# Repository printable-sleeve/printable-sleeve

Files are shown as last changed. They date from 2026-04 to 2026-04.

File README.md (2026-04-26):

# PRINTABLE-SLEEVE

**Open Source Sexual Wellness Device**

A parametric, vacuum-enabled masturbation sleeve for FDM 3D printing. Two materials.
Five parts. No proprietary components. Fully open source.

> ⚠️ **Adult use only.** This project contains technical documentation
> for a personal wellness device intended for adults.

→ [Why this project exists](WHY.md)

---

## Download ready-to-print STL files

Pre-rendered for four standard sizes. All parts per size are matched and fit together.

| Size | BORE_D | Girth | Files |
|---|---|---|---|
| **S** | 35.0 mm | ~110 mm | shell_S, cap_S, plug_S, inlay_S, cushion_S |
| **M** | 38.0 mm | ~119 mm | shell_M, cap_M, plug_M, inlay_M, cushion_M |
| **L** | 41.0 mm | ~129 mm | shell_L, cap_L, plug_L, inlay_L, cushion_L |
| **XL** | 44.0 mm | ~138 mm | shell_XL, cap_XL, plug_XL, inlay_XL, cushion_XL |

Download all STLs from the [Files page](https://github.com/printable-sleeve/printable-sleeve/tree/main/files).

Not sure which size? Wrap a soft tape around your shaft, note the girth in mm, divide by 3.14.
Pick the size closest to your result. TPU stretches slightly — when between sizes, go smaller.

---

## What you need

| | |
|---|---|
| 3D printer | FDM — e.g. Bambu Lab A1 Mini |
| Material A | PETG (shell + cap) |
| Material B | TPU Shore 95A, body-safe, phthalate-free |
| Software | [OpenSCAD](https://openscad.org) + [BOSL2 library](https://github.com/BelfrySCAD/BOSL2) |
| Accessories | Water-based lubricant, condom (recommended) |

---

## How it works

The device consists of five printed parts:

```
A) shell   → PETG rigid housing
B) cap     → PETG screw cap with vacuum port
C) plug    → TPU vacuum seal
D) inlay   → TPU sleeve with soft entry ring
E) cushion → TPU air cushion ring (optional)
```

The inlay protrudes from the front of the shell. The cap screws onto the rear.
Inserting the plug creates a vacuum inside — which applies gentle pressure
from all sides and holds the inlay in place.

---

## Custom size — build from source

### Step 1 — Measure yourself

Wrap a soft tape around your shaft. Note the girth in mm.
Divide by 3.14 → that is your diameter. Enter it as `BORE_D`.

**Example:** 124 mm girth ÷ 3.14 = **39.5 mm**

> **Note:** `BORE_D` sets the housing size, not the inlay bore directly.
> The actual bore inside the inlay is approximately `BORE_D − 6.4 mm` with default settings.
> TPU Shore 95A stretches to accommodate — this is intentional.
> Reduce `WALL_T` for a looser fit, increase for firmer.

### Step 2 — Install BOSL2

1. [Download BOSL2](https://github.com/BelfrySCAD/BOSL2/archive/refs/heads/master.zip)
2. Unzip, rename the folder to `BOSL2`
3. Copy to your OpenSCAD libraries folder:
   - **Windows:** `Documents/OpenSCAD/libraries/`
   - **Linux:** `~/.local/share/OpenSCAD/libraries/`
   - **Mac:** `~/Documents/OpenSCAD/libraries/`

### Step 3 — Customise the file

Open `PRINTABLE-SLEEVE.scad` in OpenSCAD. Change these values near the top:

```openscad
BORE_D       = 39.5;   // ← your diameter (girth ÷ 3.14)
SHRINK_COMP  = 1.00;   // ← start here, tune if inlay is too loose or tight
WALL_T       = 5.5;    // ← wall thickness (increase for firmer feel)
SHELL_LENGTH = 100.0;  // ← 80 / 100 / 120 mm
```

### Step 4 — Export each part as STL

Set `RENDER = "..."` → **Design → Export → Export as STL**

| RENDER | Material | Print time |
|---|---|---|
| `"shell"` | PETG | ~90 min |
| `"cap"` | PETG | ~60 min |
| `"plug"` | TPU | ~15 min |
| `"inlay"` | TPU | ~120 min |
| `"cushion"` | TPU | ~60 min (optional) |

Use `RENDER = "all"` to preview all parts together (not for printing).

---

## Print settings

### PETG — shell + cap

| Setting | Value |
|---|---|
| Nozzle | 250–255°C |
| Bed | 70°C, textured PEI + glue stick |
| Layer height | 0.20 mm |
| Walls | 4 |
| Infill | 40% |

### TPU Shore 95A — inlay + plug + cushion

**Filament profile** (filament → pencil icon → tabs):

| Setting | Tab | Value |
|---|---|---|
| Nozzle | Temperature | 225°C |
| Bed | Temperature | 30°C, smooth PEI |
| **Retraction length** | Retraction | **0.4 mm** ← critical |
| Flow rate | Advanced | 95% |
| Max volumetric speed | Advanced | 1.5 mm³/s |
| Wall lines | Strength | 2 |
| Infill density | Strength | 10% gyroid |
| AMS Lite | — | **DO NOT USE** — external spool only |

**Process profile:**

| Setting | Location | Value |
|---|---|---|
| Layer height | Quality | 0.20 mm |
| Seam position | Quality | Nearest |
| Wall order | Quality → Advanced | outer/inner |
| **Avoid crossing walls** | Quality → Advanced | **ON** ← critical |
| Outer wall speed | Speed | 80 mm/s |
| Inner wall speed | Speed | 80 mm/s |
| Surface speed | Speed | 80 mm/s |
| Reduce infill retraction | Other → G-Code | ON |

**Printer settings** (printer profile → Extruder tab):

| Setting | Value |
|---|---|
| Retraction length | 0.4 mm |
| Z-hop | 0.2 mm |
| Retraction/feed speed | 30 mm/s |

> **Air cushion only:** set infill to **0%** and top/bottom layers to **4**.

### Print orientation

| Part | Place on bed |
|---|---|
| Shell | upright, open end up |
| Cap | flat side down |
| Plug | grip head down, pin up |
| Inlay | insertion end down (z=0), opening up |

---

## Assembly

1. (Optional) Push air cushion ring into shell bore
2. Push inlay into shell from front until it seats on the rim
3. Screw cap onto rear thread
4. Push plug into cap vacuum port → vacuum builds up inside

---

## Use

- **Water-based lubricant only** — silicone lubricant degrades TPU
- Condom recommended (improves hygiene and feel)
- Apply lubricant to inlay bore before use

---

## Cleaning

1. Pull inlay straight out
2. Rinse with warm soapy water
3. Dry completely before reinserting
4. Shell: wipe with damp cloth — do not submerge
5. Replace inlay if you see cracks or permanent deformation

---

## Post-processing (optional)

Sand the inner bore of the inlay with wet/dry paper:
**400 grit → 800 grit → 1200 grit**
Takes 2–3 minutes. Removes seam ridges for a smoother surface.

---

## Parameters

| Parameter | Default | What it controls |
|---|---|---|
| `BORE_D` | 39.5 | Inner bore diameter [mm] — your girth ÷ 3.14 |
| `SHELL_LENGTH` | 100 | Shell length [mm] |
| `SHRINK_COMP` | 1.00 | TPU shrinkage factor — tune in 0.005 steps |
| `WALL_T` | 5.5 | Wall thickness [mm] — thicker = firmer |
| `RENDER` | "inlay" | Which part to export as STL |
| `RESOLUTION` | 64 | Render quality (64 recommended) |

---

## Troubleshooting

| Problem | Solution |
|---|---|
| Inlay too loose in shell | Increase `SHRINK_COMP` by 0.005 |
| Inlay won't fit in shell | Decrease `SHRINK_COMP` by 0.005 |
| Stringing inside bore | Retraction 0 mm + Avoid crossing walls ON |
| Surface bumps inside bore | Flow rate 92%, speed 12 mm/s |
| Vacuum won't hold | Push plug in further, tighten cap |

---

## Optional: Air Cushion Ring

Set `RENDER = "cushion"`. Insert into shell bore before the inlay.
Acts as a soft spring — compresses under load, rebounds when released.
Stack 1 or 2 rings to tune resistance.

**Critical:** infill **0%** — the hollow wall is the spring.

---

## License

**Creative Commons Attribution-ShareAlike 4.0 International (CC BY-SA 4.0)**

Free to use, modify, and share — including commercially.
Attribution required. Derivatives must carry the same license.

Full text: https://creativecommons.org/licenses/by-sa/4.0/

---

## Disclaimer

This project is provided as-is for educational and personal use.This device has not been tested, certified, or approved by any medical or regulatory body. The authors make no warranties regarding safety, fitness for purpose, or material compatibility. You are solely responsible for the materials you use, the quality of your print, and how you use the device. Use body-safe, phthalate-free TPU from a reputable supplier — the authors cannot verify third-party materials. If you experience any discomfort, discontinue use immediately. This project is not a medical device. By downloading, printing, or using this design you accept full responsibility for your own safety.

---

## Contributing

Pull requests welcome. Please keep changes parametric and document
any new parameters in the file header and in this README.

---

*printable-sleeve — Open Source Sexual Wellness*
*https://github.com/printable-sleeve*

---

This design is free. If it works for you and you'd like to support the project:
❤️ https://buymeacoffee.com/uknawn

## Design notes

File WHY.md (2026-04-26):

# Why printable-sleeve exists

Sexual wellness products are a $1.5 billion market growing at 9.5% annually.
Yet for millions of people, buying one is still out of reach — not because
the products don't exist, but because of price, stigma, and geography.

This project exists to change that.

---

## The three barriers we eliminate

### 1. Cost

A commercial masturbation sleeve costs €60–90.
The materials to print one cost €2–5.

That gap exists not because of engineering complexity, but because of
marketing, distribution, retail margins, and packaging. None of those
add any functional value for the person using it.

FDM printing eliminates all of them.

### 2. Stigma

Studies show that approximately 29% of people who want a sexual wellness
product never buy one — not because of price, but because of stigma.

The act of buying one is itself a barrier:
walking into a shop, receiving a package, seeing a charge on a bank statement.

A file you download and print at home leaves no trace.
That is not a workaround. That is a genuine solution to a real problem.

### 3. Access

A person in a rural area, a country with restrictive import laws,
or simply without disposable income has no realistic access to this
product category at commercial prices.

A 3D printer and a spool of TPU changes that.
The design travels as a file. Manufacturing happens locally, on demand.

---

## The health case

This is not just about convenience or cost. There is a documented
public health argument.

A study published in European Urology (Rider et al., 2016, based on
Harvard/Health Professionals Follow-up data) found that men who
ejaculated 21 or more times per month had a 20% lower risk of
prostate cancer compared to those who ejaculated 4–7 times per month.

Separate research consistently links sexual activity and orgasm with
reduced cortisol levels, improved sleep quality, and lower cardiovascular
stress markers.

Access to appropriate tools matters for these outcomes.
A product that is unaffordable or inaccessible is not a solution.

---

## Why open source

Commercial products in this category are closed, proprietary, and
designed to be replaced rather than repaired or customised.

Open source means:
- Anyone can adapt the design for their body
- Anyone can improve it and share the improvement
- No company can restrict access or raise prices
- The design survives its creator

We use CC BY-SA 4.0. You can use this design, modify it, and even
sell prints of it — as long as you keep it open under the same terms.

---

## Why now

Two things made this possible:

**Bambu Lab (2022–2024)** democratised FDM printing. A machine that
produces reliable, accurate prints at 15 mm/s in TPU now costs under €200.
That did not exist five years ago.

**OpenSCAD + BOSL2** makes the design fully parametric. One number —
your girth divided by 3.14 — adapts the entire geometry to your body.
No CAD skills required.

The technology was always theoretically possible. Now it is practical.

---

## What this is not

This is not a replacement for human connection.
This is not a statement about relationships or sexuality.
This is a functional object, designed to be printed, used, and improved.

The same argument that applies here applies to any product where:
- There is a large gap between manufacturing cost and retail price
- Stigma reduces access for people who would benefit
- The underlying technology is now accessible to individuals

Sexual wellness happens to be a particularly clear example.
But the principle is general.

---

## Contributing

If you improve this design, please share it under the same license.
If you print it and have feedback, open an issue.
If you know someone who would benefit from this, share the link.

That is how open source works.

---

*printable-sleeve — Open Source Sexual Wellness*
*CC BY-SA 4.0 — https://github.com/printable-sleeve*

---

This design is free. If it works for you and you'd like to support the project:
❤️ https://buymeacoffee.com/uknawn

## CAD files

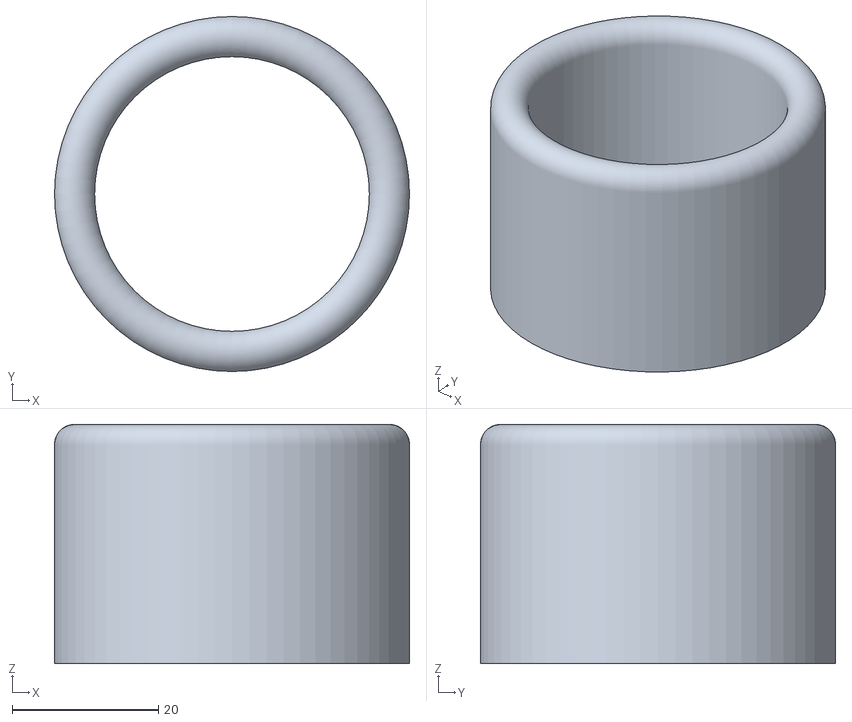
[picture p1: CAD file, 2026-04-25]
files/inlay_XL.stl
48.6 x 48.6 x 32.8

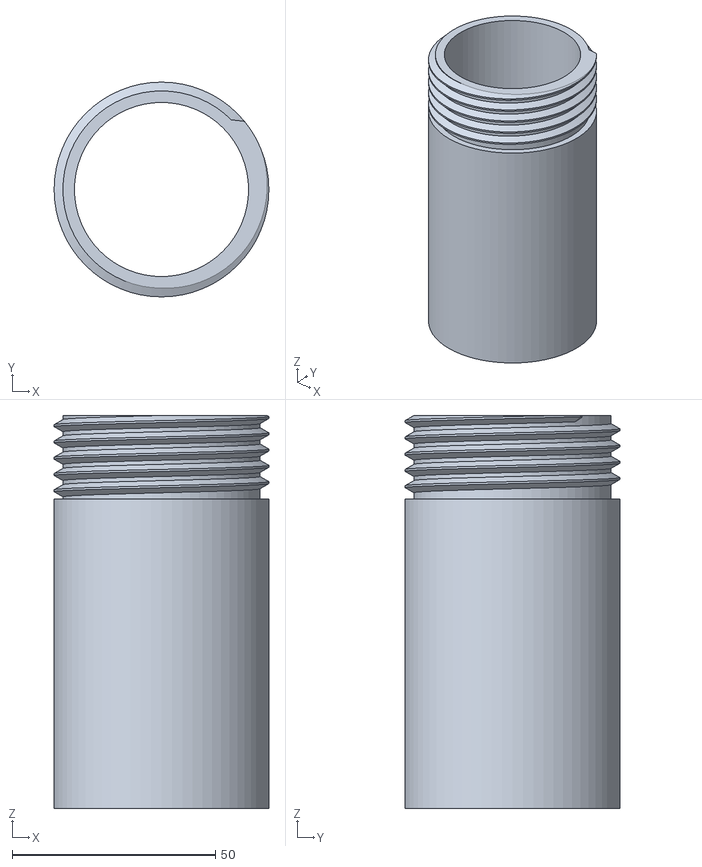
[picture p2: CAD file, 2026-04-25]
files/shell_M.stl
52.8 x 52.8 x 96.6

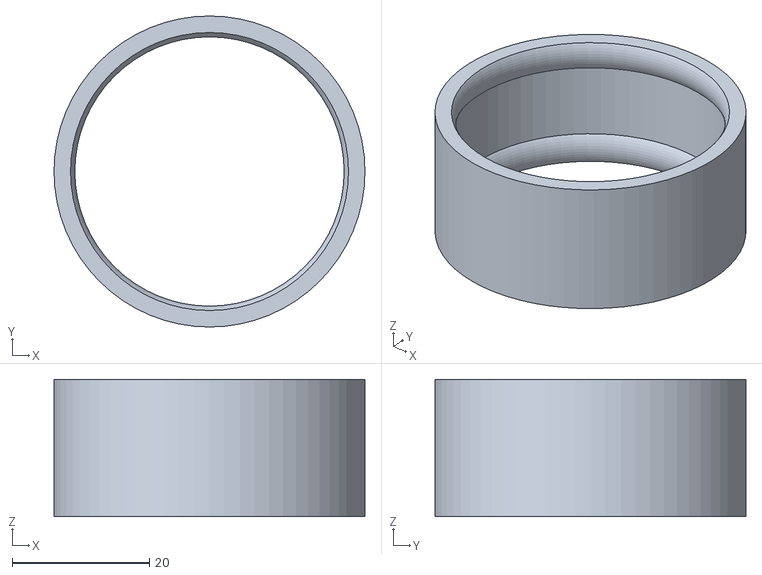
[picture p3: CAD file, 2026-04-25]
files/cushion_L.stl
45.4 x 45.4 x 20.0

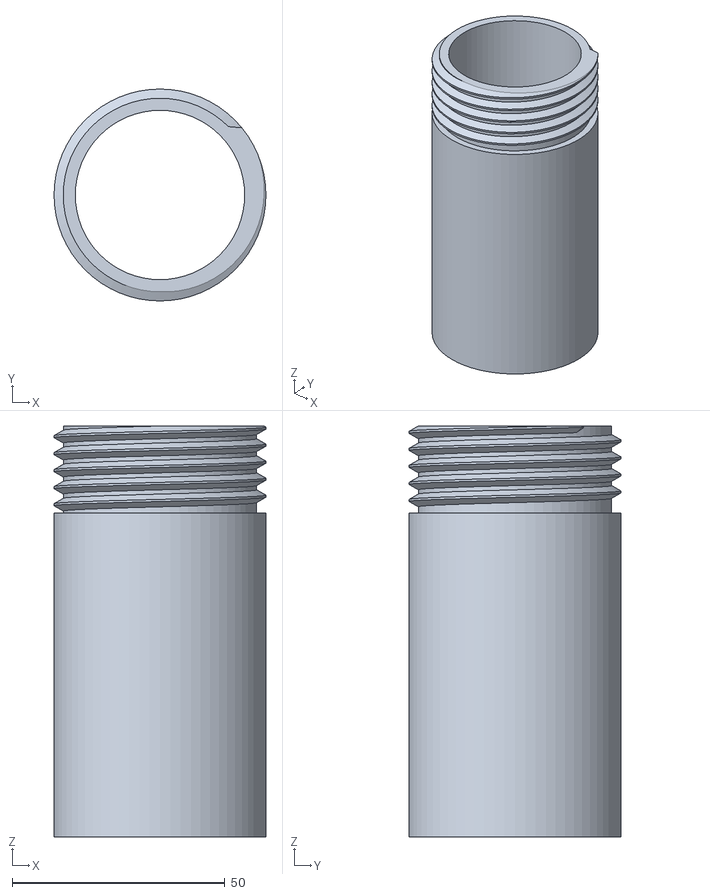
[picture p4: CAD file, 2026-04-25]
files/shell_S.stl
49.8 x 49.8 x 96.6

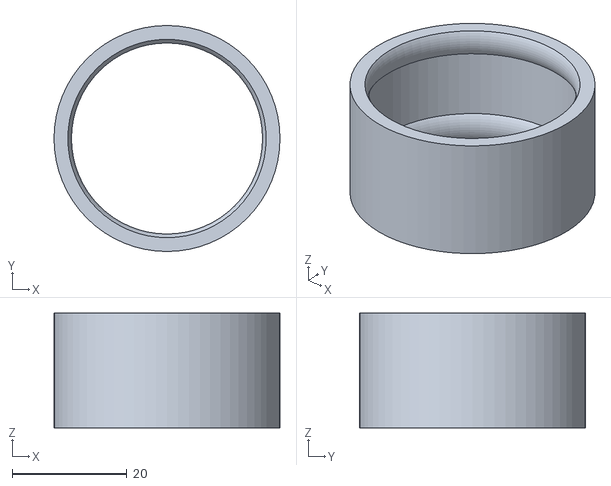
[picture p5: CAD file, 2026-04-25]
files/cushion_S.stl
39.4 x 39.4 x 20.0

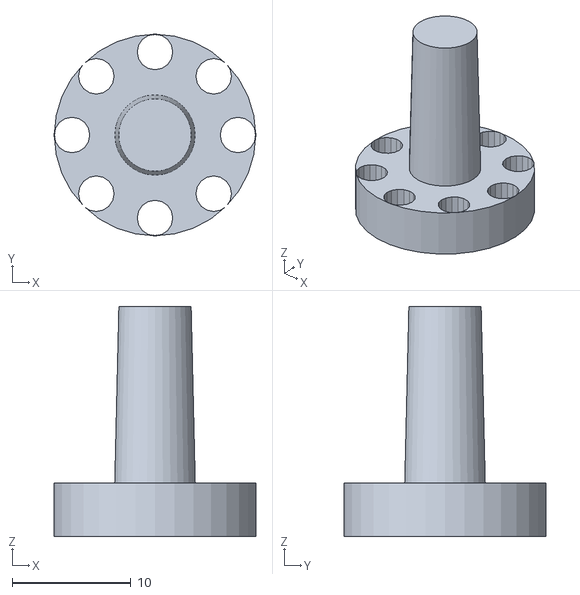
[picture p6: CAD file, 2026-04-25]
files/plug_S.stl
17.0 x 17.0 x 19.4

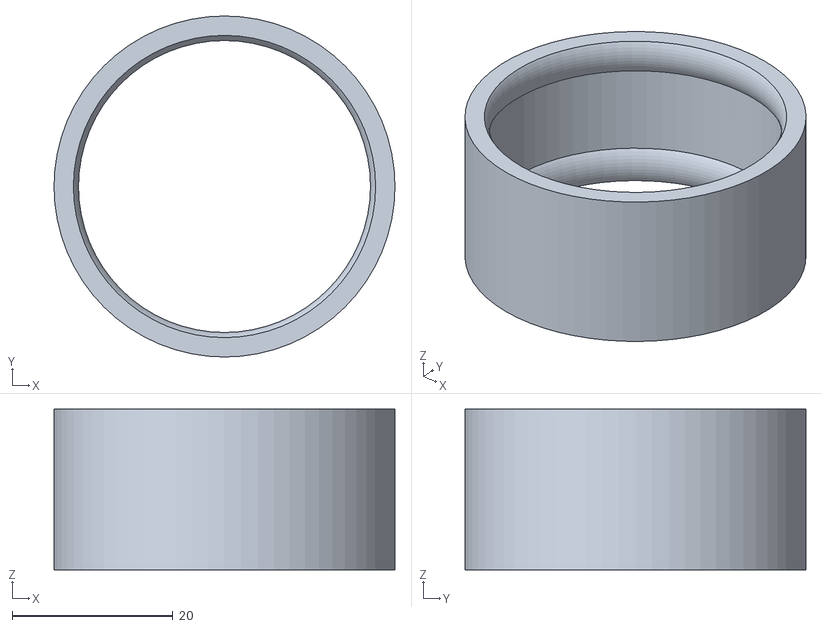
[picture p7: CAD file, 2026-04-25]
files/cushion_M.stl
42.4 x 42.4 x 20.0

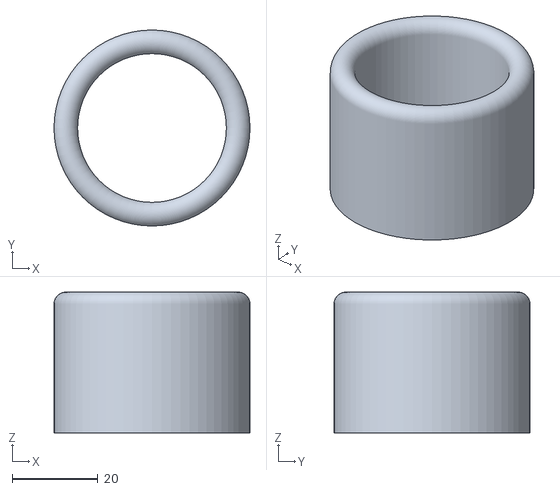
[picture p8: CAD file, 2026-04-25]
files/inlay_L.stl
45.6 x 45.6 x 32.8

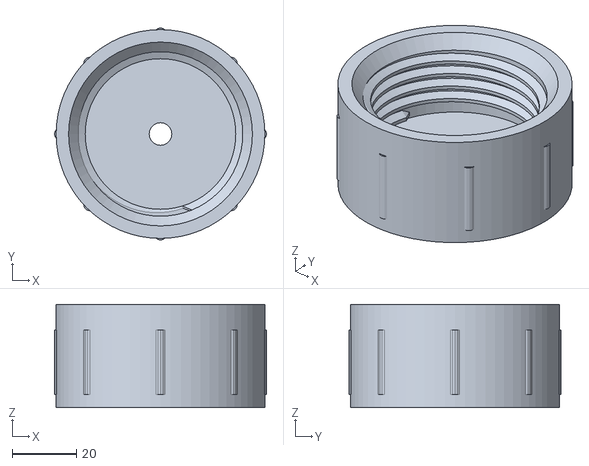
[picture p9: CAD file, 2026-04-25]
files/cap_S.stl
65.8 x 65.8 x 32.0

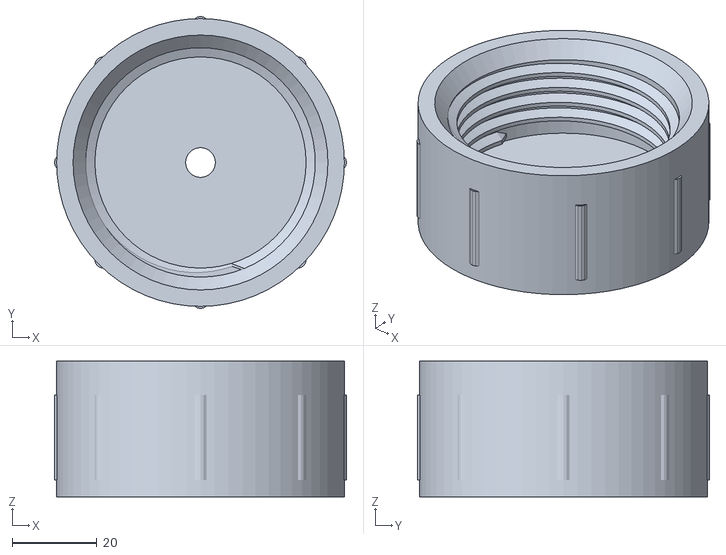
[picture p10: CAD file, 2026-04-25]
files/cap_M.stl
68.8 x 68.8 x 32.0

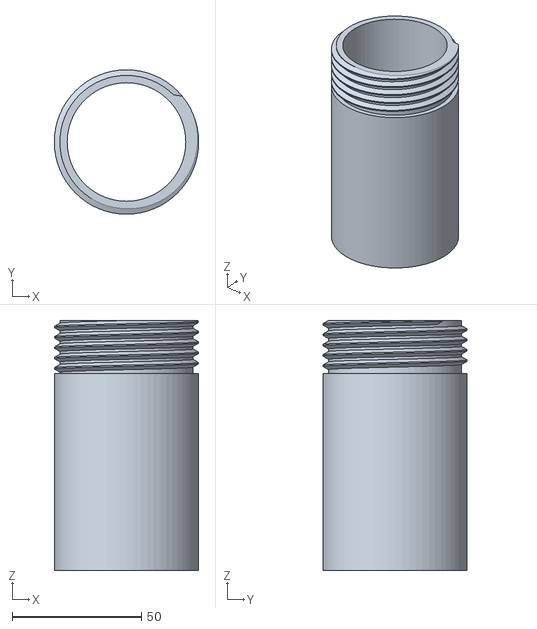
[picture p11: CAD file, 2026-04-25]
files/shell_L.stl
55.8 x 55.8 x 96.6

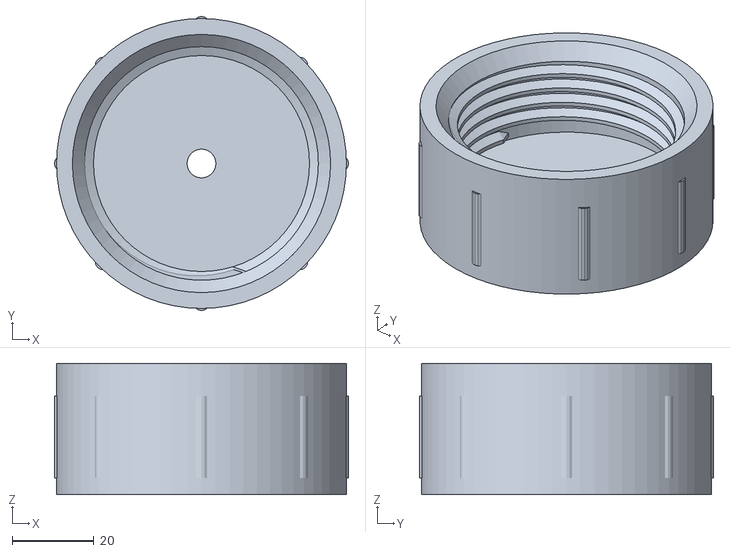
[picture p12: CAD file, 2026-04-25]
files/cap_L.stl
71.8 x 71.8 x 32.0

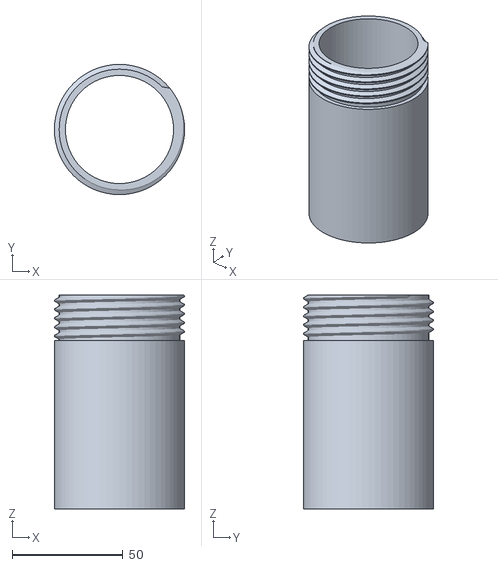
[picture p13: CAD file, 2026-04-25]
files/shell_XL.stl
58.8 x 58.8 x 96.6

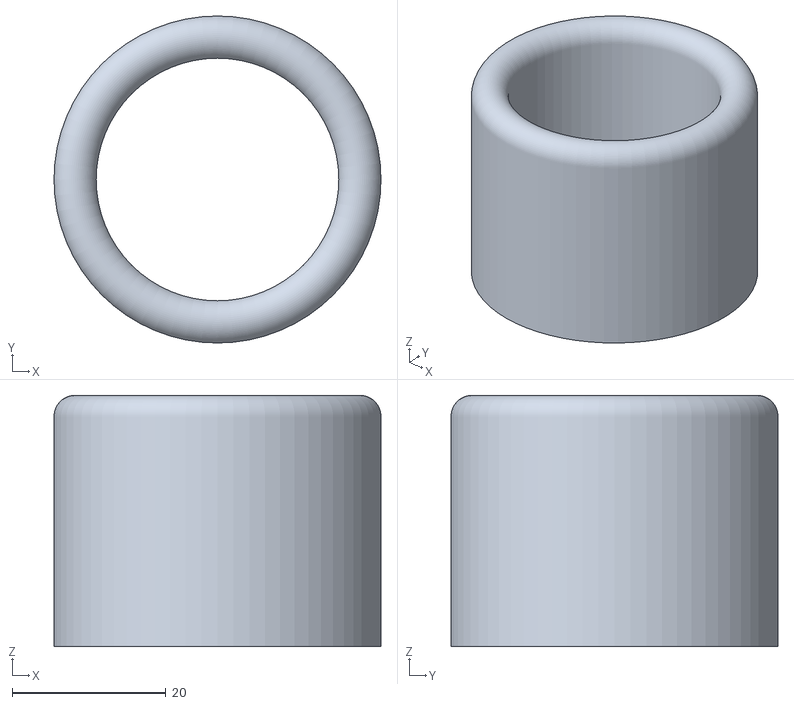
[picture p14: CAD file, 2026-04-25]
files/inlay_M.stl
42.6 x 42.6 x 32.8

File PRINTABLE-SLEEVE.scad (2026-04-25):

include <BOSL2/std.scad>
include <BOSL2/threading.scad>

/* ============================================================================
   printable-sleeve v1.2 – Open Source Sexual Wellness Device
   ============================================================================
   License  : CC BY-SA 4.0
   Project  : https://github.com/printable-sleeve
   Author   : uknawn
   Printer  : Bambu Lab A1 Mini (settings below)
   Support  : https://buymeacoffee.com/uknawn

   WHAT IT IS:
     A parametric, vacuum-enabled masturbation sleeve for FDM 3D printing.
     Two materials. Five parts. No proprietary components required.
     Designed to be printed at home, privately, at minimal cost.

   PARTS:
     A) shell   (RENDER = "shell")   – PETG rigid outer housing
     B) cap     (RENDER = "cap")     – PETG screw cap with vacuum port
     C) plug    (RENDER = "plug")    – TPU vacuum seal plug
     D) inlay   (RENDER = "inlay")   – TPU sleeve, protrudes from front
     E) cushion (RENDER = "cushion") – TPU optional air cushion ring

   HOW TO CUSTOMISE:
     1. Measure your girth in mm, divide by 3.14 → enter as BORE_D
     2. Set SHRINK_COMP based on your TPU brand (start at 1.00, tune up)
     3. Render each part separately → export as STL → slice → print

   ASSEMBLY:
     1. Push inlay into shell from front until it seats on the rim
     2. Screw cap onto rear thread
     3. Push plug into cap vacuum port → vacuum builds up inside
     4. To remove inlay: pull straight out

   ============================================================================
   PRINT SETTINGS — BAMBU LAB A1 MINI
   ============================================================================

   PETG (shell + cap):
     Nozzle temperature     : 250–255°C
     Bed temperature        : 70°C, textured PEI plate + glue stick
     Layer height           : 0.20mm
     Wall lines             : 4 or more
     Infill density         : 40%
     AMS                    : compatible

   TPU Shore 95A (inlay + plug + cushion):
     Nozzle temperature     : 225°C
     Bed temperature        : 30°C, smooth PEI plate
     Layer height           : 0.2mm  (smoother inner surface)
     Wall lines             : 2
     Infill density         : 10% gyroid
     AMS Lite               : DO NOT USE — feed from external spool only
                              TPU jams the AMS Lite hub reliably

   FILAMENT PROFILE (left sidebar → filament → pencil icon):
     Retraction length      : 0.4 mm
     Flow rate              : 95%   ← compensates TPU over-extrusion
     Max volumetric speed   : 1.5 mm³/s  ← prevents pressure spikes

   PROCESS PROFILE (right sidebar → Process):
     Seam position          : Nearest
     Wall order             : outer/inner
     Avoid crossing walls   : ON  ← CRITICAL — prevents stringing
     Outer wall speed       : 80 mm/s
     Inner wall speed       : 80 mm/s
     Surface speed          : 80 mm/s
     Reduce infill retract  : ON

   PRINTER SETTINGS (printer profile → Extruder tab):
     Retraction length      : 0.4 mm
     Z-hop on retract       : 0.2 mm
     Retraction speed       : 30 mm/s

   AIR CUSHION (RENDER = "cushion") — special settings:
     Infill density         : 0%  ← hollow = the function
     Top/Bottom layers      : 4   ← airtight seal

   PRINT ORIENTATION:
     Shell   → upright, open end facing up (no supports needed)
     Cap     → flat side on bed, threads face up (no supports needed)
     Plug    → grip head on bed, pin faces up (no supports needed)
     Inlay   → insertion end on bed (z=0 down), opening faces up (no supports)

   POST-PROCESSING (optional but recommended):
     Sand inner bore of inlay: 400 → 800 → 1200 grit wet/dry paper
     Takes 2–3 minutes. Removes seam ridge and any surface artifacts.

   ============================================================================
   HYGIENE & SAFETY
   ============================================================================
     - ALWAYS use a condom + water-based lubricant
     - DO NOT use silicone lubricant — it degrades TPU
     - Remove inlay after use, rinse with warm soapy water, dry completely
     - Replace inlay if surface shows cracks or permanent deformation
     - PETG shell: wipe clean with damp cloth, do not submerge

   ============================================================================
   TROUBLESHOOTING
   ============================================================================
     Inlay too loose in shell  → increase SHRINK_COMP by 0.005
     Inlay won't fit in shell  → decrease SHRINK_COMP by 0.005
     Stringing inside bore     → confirm: retraction OFF, crossing walls OFF
     Surface bumps inside      → reduce flow rate to 92%, speed to 12 mm/s
     Vacuum won't hold         → push plug in further, tighten cap

   REQUIRED LIBRARY — BOSL2:
     Install: https://github.com/BelfrySCAD/BOSL2
     Download ZIP → unpack → rename folder to BOSL2 → copy to:
       Windows : Documents/OpenSCAD/libraries/
       Linux   : ~/.local/share/OpenSCAD/libraries/
       Mac     : ~/Documents/OpenSCAD/libraries/
   ============================================================================ */


// ============================================================================
//  RENDER CONTROL
// ============================================================================

RENDER = "all";
// Which part to render and export as STL:
//   "shell"   → PETG outer housing
//   "cap"     → PETG screw cap
//   "plug"    → TPU vacuum plug
//   "inlay"   → TPU sleeve (main part — print this first)
//   "cushion" → TPU air cushion ring (optional, insert before inlay)
//   "all"     → all parts laid out on print bed (preview only)


// ============================================================================
//  USER PARAMETERS — edit these to customise for your body
// ============================================================================

BORE_D = 39.5;
// Inner bore diameter [mm].
// How to measure: wrap a soft tape around your shaft, note girth in mm,
// divide by 3.14 → that is your diameter.
// Example: 124mm girth ÷ 3.14 = 39.5mm
// Tip: match your measurement exactly — TPU wall gives ~2mm of flex.

SHELL_LENGTH = 100.0;
// Total shell length [mm].
// Recommended values:
//   80mm  → compact, discreet
//   100mm → standard (recommended)
//   120mm → extended

SHRINK_COMP = 1.00;
// TPU shrinkage compensation factor.
// TPU shrinks slightly when cooling. This factor scales outer dimensions up
// so the printed part ends up the right size.
//   1.00 = no compensation (good starting point — tune from here)
//   1.01 = +1% (try if inlay is too loose in shell)
//   1.06 = +6% (high-shrink brands)
// Tune in steps of 0.005. Print the plug first as a test piece.

WALL_T = 5.5;
// Inlay wall thickness [mm].
// This single value controls:
//   - How thick the tube wall is
//   - The size of the rounded entry ring (LIP_R = WALL_T / 2)
//   - The inner bore diameter (BODY_ID = BODY_OD - 2 × WALL_T)
// Thicker = stiffer, more structure. Thinner = softer, more flex.
// Minimum safe value: 3.0mm (below this, texture may cut through wall)
// Recommended: 4.0–6.0mm for Shore 95A TPU

RESOLUTION = 64;
// Circle resolution ($fn). Higher = smoother curves, slower render.
//   32  = fast preview
//   64  = recommended (good quality, reasonable render time)
//   128 = high quality, slow


// ============================================================================
//  DERIVED GEOMETRY — do not edit below this line
// ============================================================================

$fn = RESOLUTION;

// Shell geometry
SHELL_BORE    = BORE_D + 2*2.2 + 0.4; // PETG inner bore = bore + 2×wall + clearance
SHELL_OD      = SHELL_BORE + 10.0;    // shell outer diameter (10mm wall)
THREAD_LENGTH = 22.0;                  // rear thread length [mm]
THREAD_PITCH  = 4.0;                   // thread pitch [mm/turn]

// Inlay geometry — all derived from BORE_D, WALL_T, SHRINK_COMP
INLAY_LENGTH  = 30.0;                  // total inlay length [mm]
INLAY_INSIDE  = 10.0;                  // mm inside shell bore (friction fit)
// INLAY_LENGTH - INLAY_INSIDE = 20mm protrudes from shell front

BODY_OD       = (SHELL_BORE - 0.2) * SHRINK_COMP;  // outer Ø (shrink-compensated)
BODY_ID       = BODY_OD - 2 * WALL_T;               // inner bore Ø
RING_R        = WALL_T / 2;                          // entry ring torus radius
RING_CENTER   = BODY_OD/2 - RING_R;                 // torus centre from axis

// Cushion geometry
CUSHION_OD    = SHELL_BORE - 0.4;     // fits inside shell bore
CUSHION_ID    = BORE_D + 0.3;         // open bore (same as inlay)
CUSHION_L     = 20.0;                  // cushion length [mm]
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

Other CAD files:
files/plug_M.stl
files/plug_XL.stl
files/cushion_XL.stl
files/inlay_S.stl
files/cap_XL.stl
files/plug_L.stl
